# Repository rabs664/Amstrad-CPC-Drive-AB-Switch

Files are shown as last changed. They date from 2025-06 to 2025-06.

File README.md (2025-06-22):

# Amstrad-CPC-Drive-AB-Switch
 
Some Amstrad CPC software will not run on an external drive, Drive B, as it expects to run on the internal drive, Drive A.

This can be rectified by adding a header to the floppy ribbon cable and inserting a small switch to pull Drive Select 1 low.



Information regarding this can be found in the [CPCWiki Guide on how to connect a 3.5" drive to a CPC 6128](https://www.cpcwiki.eu/index.php?title=Guide_on_how_to_connect_a_3.5%22_drive_to_a_CPC6128/664)

This CPCWiki guide discusses an option to make the external drive the Primary Drive by connecting pin 11 to 12 on the cable where pin 12 is the Shugart standard numbering system for Drive Select 1, see [CPCWkiki Guide for the 2nd disc drive connector](https://www.cpcwiki.eu/index.php/Connector:2nd_disc_drive_(CPC664,_CPC6128,_CPC6128%2B)). Pin 11 is GND.

However, adding a header and switch is not always an option for a user.

This small PCB effectively acts as the switch in the ribbon cable, pulling Drive Select 1 low and allowing software which expects to run on Drive A, to run on Drive B.

 

The PCB then sits between the second floppy drive edge connector and the floppy drive ribbon cable.

 

>[!IMPORTANT]
>However, there are some restrictions on its use which should be noted and are detailed in the [CPCWiki Guide on how to connect a 3.5" drive to a CPC 6128](https://www.cpcwiki.eu/index.php?). 
>Primairly you cannot have anything inserted into Drive A when the switch is in the ON position but also the switch should only be moved to the ON position when the CPC is on and OFF when the CPC is powered off. The [CPCWiki Guide](https://www.cpcwiki.eu/index.php?) talks of a "drives-act-as-one error on next bootup" if the switch is left ON when powering the CPC on but I have never observed this.

>[!CAUTION]
>USE AT YOUR OWN RISK.
>There is always the risk that the switch can cause harm to your CPC. Although I have tested the switch, there is no guarantee that it will work properly under all circumstances.

>[!NOTE]
>This repository contains the associated Kicad project and Gerber files should you want to create the switch. A DigiKey list for the switch and edge connector can be found [here](https://www.digikey.co.uk/en/mylists/list/OB2QHATDFZ). Although the switch is not an ideal fit.

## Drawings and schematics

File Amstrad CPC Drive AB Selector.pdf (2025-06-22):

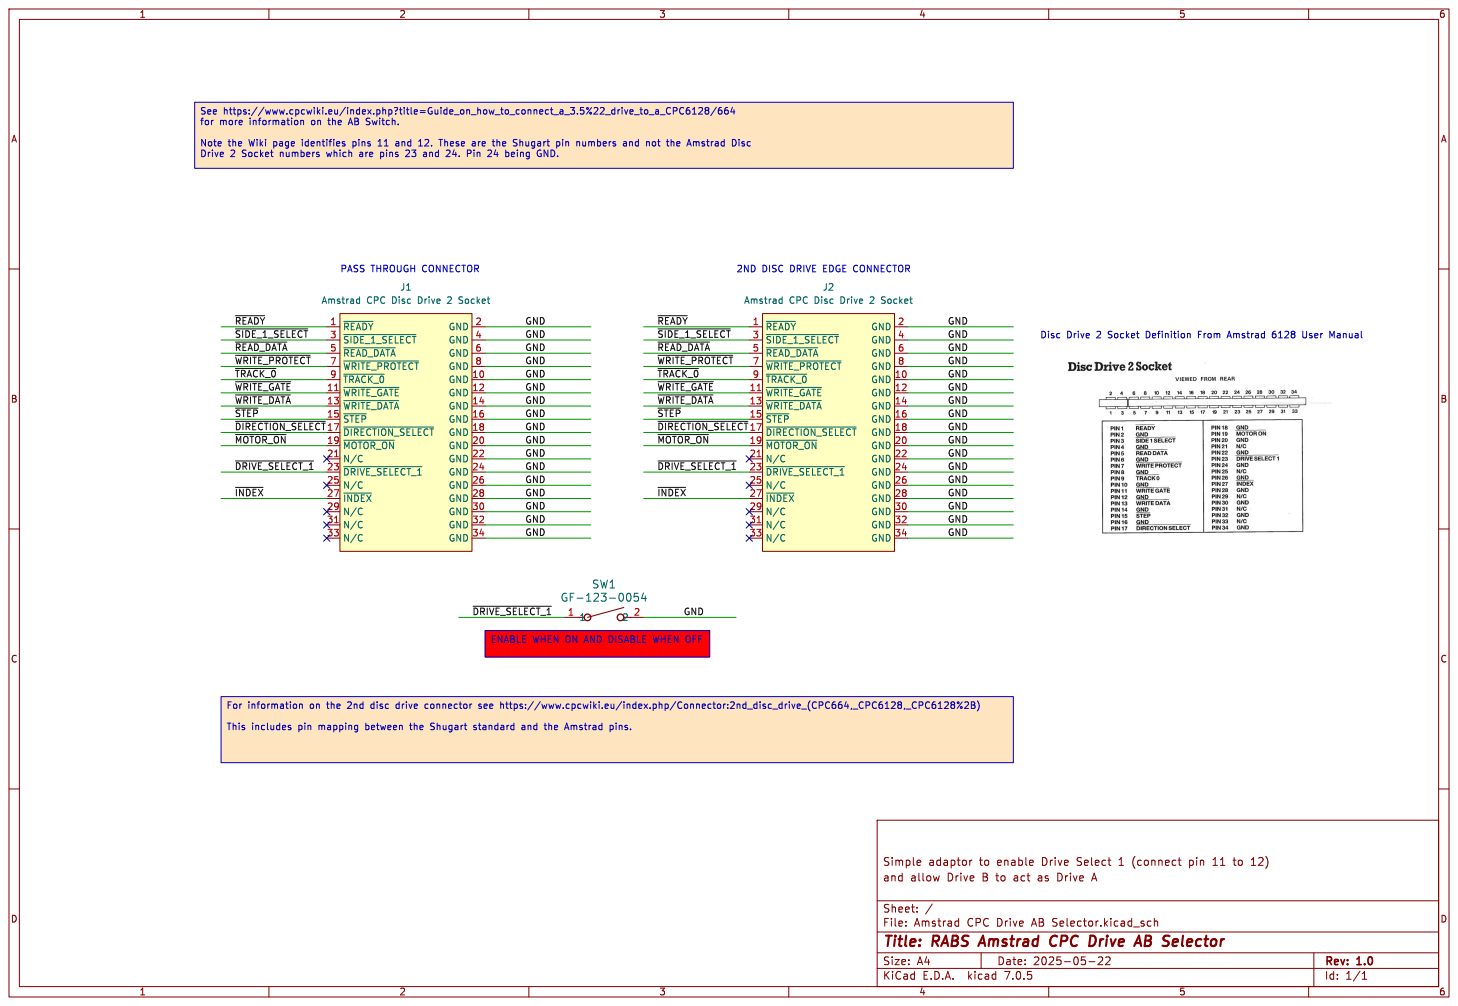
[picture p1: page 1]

See https://www.cpcwiki.eu/index.php?title=Guide_on_how_to_connect_a_3.5%22_drive_to_a_CPC6128/664

~{INDEX} GND GND GND

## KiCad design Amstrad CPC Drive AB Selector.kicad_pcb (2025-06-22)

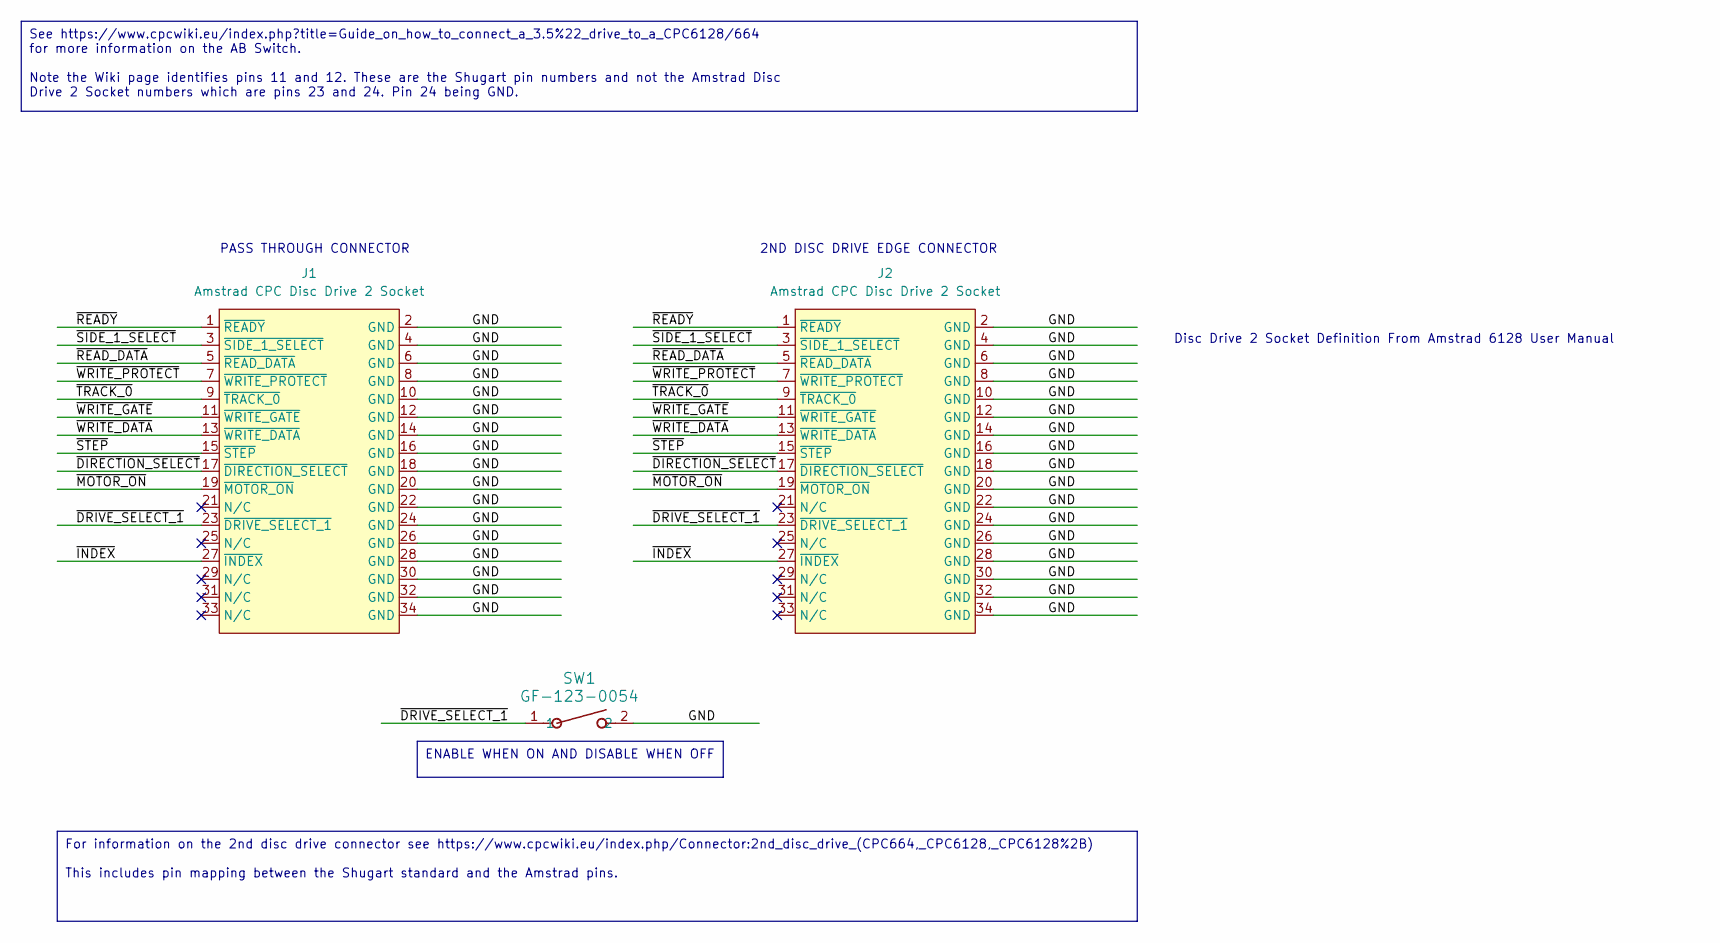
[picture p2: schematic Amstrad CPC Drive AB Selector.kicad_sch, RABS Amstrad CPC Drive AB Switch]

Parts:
J1, J2: Amstrad CPC Disc Drive 2 Socket; Amstrad_CPC_Disc_Drive_2_socket
SW1: GF-123-0054; SW2_GF-123-0054_CWI

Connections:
/GND: J1.2 (GND), J1.4 (GND), J1.6 (GND), J1.8 (GND), J1.10 (GND), J1.12 (GND), J1.14 (GND), J1.16 (GND), J1.18 (GND), J1.20 (GND), J1.22 (GND), J1.24 (GND), J1.26 (GND), J1.28 (GND), J1.30 (GND), J1.32 (GND), J1.34 (GND), J2.2 (GND), J2.4 (GND), J2.6 (GND), J2.8 (GND), J2.10 (GND), J2.12 (GND), J2.14 (GND), J2.16 (GND), J2.18 (GND), J2.20 (GND), J2.22 (GND), J2.24 (GND), J2.26 (GND), J2.28 (GND), J2.30 (GND), J2.32 (GND), J2.34 (GND), SW1.2
/~DIRECTION_SELECT: J1.17 (~DIRECTION_SELECT), J2.17 (~DIRECTION_SELECT)
/~DRIVE_SELECT_1: J1.23 (~DRIVE_SELECT_1), J2.23 (~DRIVE_SELECT_1), SW1.1
/~INDEX: J1.27 (~INDEX), J2.27 (~INDEX)
/~MOTOR_ON: J1.19 (~MOTOR_ON), J2.19 (~MOTOR_ON)
/~READY: J1.1 (~READY), J2.1 (~READY)
/~READ_DATA: J1.5 (~READ_DATA), J2.5 (~READ_DATA)
/~SIDE_1_SELECT: J1.3 (~SIDE_1_SELECT), J2.3 (~SIDE_1_SELECT)
/~STEP: J1.15 (~STEP), J2.15 (~STEP)
/~TRACK_0: J1.9 (~TRACK_0), J2.9 (~TRACK_0)
/~WRITE_DATA: J1.13 (~WRITE_DATA), J2.13 (~WRITE_DATA)
/~WRITE_GATE: J1.11 (~WRITE_GATE), J2.11 (~WRITE_GATE)
/~WRITE_PROTECT: J1.7 (~WRITE_PROTECT), J2.7 (~WRITE_PROTECT)

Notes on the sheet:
See https://www.cpcwiki.eu/index.php?title=Guide_on_how_to_connect_a_3.5%22_drive_to_a_CPC6128/664 for more information on the AB Switch. Note the Wiki page identifies pins 11 and 12. These are the Shugart pin numbers and not the Amstrad Disc Drive 2 Socket numbers which are pins 23 and 24. Pin 24 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
For information on the 2nd disc drive connector see https://www.cpcwiki.eu/index.php/Connector:2nd_disc_drive_(CPC664,_CPC6128,_CPC6128%2B) This includes pin mapping between the Shugart standard and the Amstrad pins.
ENABLE WHEN ON AND DISABLE WHEN OFF
PASS THROUGH CONNECTOR
2ND DISC DRIVE EDGE CONNECTOR
Disc Drive 2 Socket Definition From Amstrad 6128 User Manual

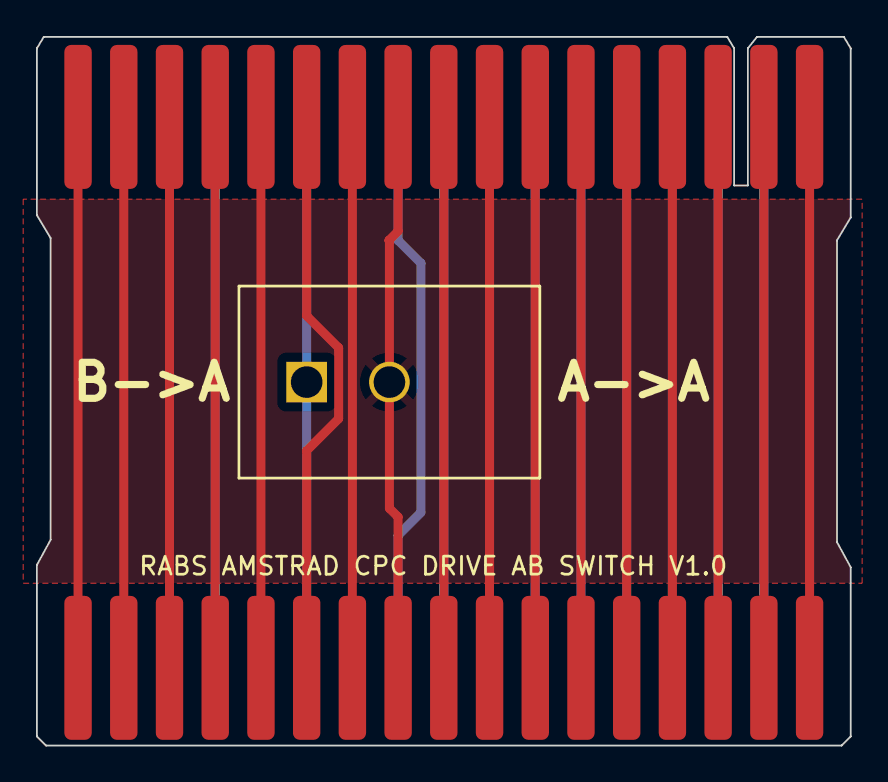
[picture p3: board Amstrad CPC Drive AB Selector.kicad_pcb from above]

Board: 2 copper layers, 45.2 x 39.4 mm, 3 parts (0 on the bottom side), 13 nets.

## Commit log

2025-06-23 Added footprint for Disc Drive 2 socket
2025-11-03 Update usage instructions for drive switch
    Clarified usage restrictions for the drive switch in the README.
